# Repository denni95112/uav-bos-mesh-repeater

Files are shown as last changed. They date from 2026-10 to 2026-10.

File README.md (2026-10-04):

# UAV-BOS Mesh-Repeater

LoRa-Repeater für die [UAV-BOS-Tracker](https://github.com/denni95112/uav-bos-hardware-tracker).
Er sendet keine eigene Position und hat kein GPS.
Er leitet die Funkpakete der Tracker weiter, mit demselben Meshtastic-kompatiblen Protokoll
wie die Tracker-Firmware.

- Tracker: [uav-bos-hardware-tracker](https://github.com/denni95112/uav-bos-hardware-tracker)
- Hardware: Heltec **WiFi LoRa 32 V2**, 868 MHz (ESP32, SX1276, OLED)
- Firmware: PlatformIO + Arduino (`src/`)
- Gehäuse: OpenSCAD (`case/repeater_case.scad`), Druckdateien `case/base.stl` und `case/lid.stl`

Die 433-MHz- und 915-MHz-Varianten des Boards passen nicht. Das Frequenzband ist fest EU 868.

> **Firmware ganz einfach aufspielen:** Repeater per Micro-USB anschließen und auf
> [ubhtwf.open-drone-tools.de](https://ubhtwf.open-drone-tools.de/?board=repeater) auf **Installieren** klicken.
> Das funktioniert direkt im Browser (Google Chrome oder Microsoft Edge am PC), ohne Software-Installation.

## Betriebsarten

| Betriebsart | WLAN | LoRa |
|---|---|---|
| Repeater + WLAN | nur Config-AP, kein Router | leitet weiter |
| Repeater ohne WLAN | aus | leitet weiter |

Der Access Point heißt **`UAV-BOS-Repeater-XXXX`**. Die Seite ist `http://192.168.4.1`.
Beim ersten Start ist "Repeater + WLAN" aktiv, damit sich das Gerät einrichten lässt.

- **PRG kurz**: Betriebsart wechseln. Die Auswahl gilt 3 Sekunden nach dem letzten Druck.
- **PRG 3 Sekunden**: OLED an oder aus. Der Funk läuft weiter.

Aus "Repeater ohne WLAN" kommt man mit einem kurzen Tastendruck zurück zum Config-AP.

## Einrichtung

1. Repeater per Micro-USB an den PC (Datenkabel). Firmware im Browser aufspielen:
   [ubhtwf.open-drone-tools.de](https://ubhtwf.open-drone-tools.de/?board=repeater), **Installieren**.
   Falls kein Port erscheint: **PRG** halten, kurz **RST** drücken, **PRG** loslassen, erneut auf Installieren klicken.
   Alternativ mit PlatformIO, siehe [Bauen](#bauen).
2. Mit dem WLAN `UAV-BOS-Repeater-XXXX` verbinden und `http://192.168.4.1` öffnen.
3. Dieselben LoRa-Werte eintragen wie bei den Trackern:
   - Modemprofil (Standard LongFast)
   - Frequenz-Slot
   - Hop-Limit
   - Sendeleistung (2–17 oder **20 dBm**; 18 und 19 werden zu 17. Der Tracker-SX1262 darf 22)
   - Weiterleitung: "Alle Pakete", "Nur UAV-BOS-Tracker" oder "Keine"
   - Sendezeit für fremde Pakete
   - **Mesh-Schlüssel**, identisch zu den Trackern
4. Optional ein AP-Passwort (mindestens 8 Zeichen, Benutzer `admin`).
5. Speichern. Das Gerät startet neu.

Ohne denselben Schlüssel erkennt der Repeater den UAV-BOS-Kanal nicht. "Alle Pakete" leitet
fremde Meshtastic-Pakete trotzdem weiter. "Nur UAV-BOS-Tracker" braucht den Schlüssel.

Der Repeater schickt alle 15 Minuten ein Hello mit Hop 0, damit die Tracker ihn als eigenen
Relay erkennen. Das Hello wird nicht weitergeflutet.

## Funk

Gleiche Vorgaben wie die Tracker-Firmware:

- EU_868, Sync-Word `0x2B`, Präambel 16
- Profile ShortFast, ShortSlow, MediumFast, MediumSlow, LongFast, LongModerate, LongSlow
- 250-kHz-Profile senden auf 869,525 MHz. 125-kHz-Profile nutzen Slot 1 (869,4625 MHz) oder Slot 2 (869,5875 MHz)
- 10 % Sendezeit im Band 869,4–869,65 MHz. Fremde Pakete stoppen früher, Tracker-Pakete haben Vorrang
- Kanalname `UAV-BOS`

**Schlüssel in der Firmware (optional):** `MESH_PSK_B64` in `.env` (Vorlage `.env.example`) oder als
Umgebungsvariable. Ein Gerät ohne gespeicherten Schlüssel übernimmt ihn einmalig. Der Wert steht
lesbar in der Binärdatei. Solche Builds nicht veröffentlichen.

## Gehäuse (`case/repeater_case.scad`)

Für die Heltec WiFi LoRa 32 V2 und einen LiPo 35 × 20,1 × 6,5 mm. Der Akku liegt unter dem
Display-Ende, die Platine auf seitlichen Auflagen. Ohne Stiftleisten: eine gelötete Leiste ist
höher als der Deckel. Fertige Druckdateien liegen in `case/`: `base.stl` und `lid.stl`.

Außenmaße: 63,8 × 29,9 × 23,5 mm.

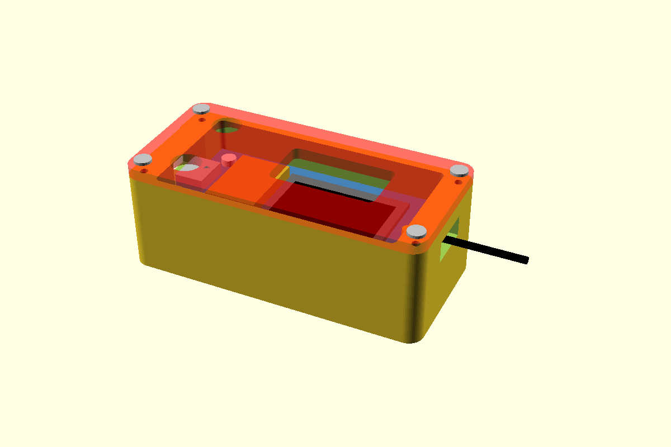
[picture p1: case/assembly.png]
Zusammenbau


Die Öffnungen sind an einem V2-Board gemessen, ab der Platinenkante an der USB-Seite.
"Links" heißt: von oben gesehen, USB-Buchse zeigt zu dir.

| Parameter | Standard / Bedeutung |
|---|---|
| `pcb_l`, `pcb_w` | 51 × 25,5 mm Platine |
| `bat_l`, `bat_w`, `bat_h` | 35 × 20,1 × 6,5 mm LiPo |
| `bottom_clear` | 4,8 mm Luft zwischen Akkuoberfläche und Platinenunterseite. Größer, wenn der Funkschirm den Akku berührt |
| `top_clear` | 7,0 mm über der Platinenoberseite für OLED und ESP32-Modul. Größer, wenn der Deckel auf das Display drückt |
| `oled_cx`, `oled_cy`, `oled_lx`, `oled_ly` | Displayfenster, Mitte ab USB-Kante und PRG-Kante |
| `prg_x`, `prg_y`, `rst_x`, `rst_y` | Tastenmitten. Das markierte Loch ist PRG |
| `usb_w`, `usb_h` | Micro-USB-Öffnung |
| `ant_w`, `ant_h` | Schlitz am Display-Ende für das U.FL-Antennenkabel |

Export:

```
openscad -o case/base.stl -D 'part="base"' case/repeater_case.scad
openscad -o case/lid.stl  -D 'part="lid"'  case/repeater_case.scad
```

`part="assembly"` zeigt das zusammengebaute Gerät mit Platine, Akku und Deckel.
`part="both"` legt Unterteil und Deckel nebeneinander zum Drucken.

Zusammenbau: Akku vom USB-Ende unter die beiden Lippen schieben und an der Buchse auf der
Unterseite einstecken. Platine gegen das Antennenende legen, Deckel aufsetzen und mit
4× M2×8 Zylinderkopfschrauben schließen. Die LoRa-Antenne führt durch den Schlitz am
Display-Ende nach außen. Das markierte Loch ist PRG (USB zeigt zu dir: links).

Druck in PETG oder PLA, 0,2 mm Schichthöhe, 3 Wände, keine Stützen. Der Deckel ist in der
STL schon kopfüber, die Oberseite liegt auf dem Druckbett.

## Bauen

```
pio run -e heltec_v2
pio run -e heltec_v2 -t upload
```

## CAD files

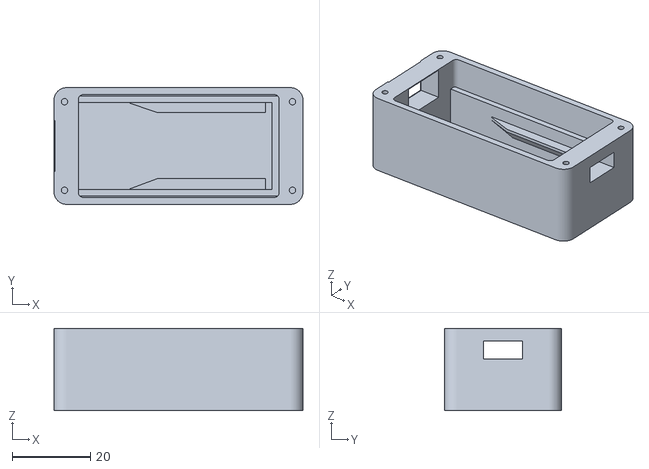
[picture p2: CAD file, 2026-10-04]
case/base.stl
63.8 x 29.9 x 21.1

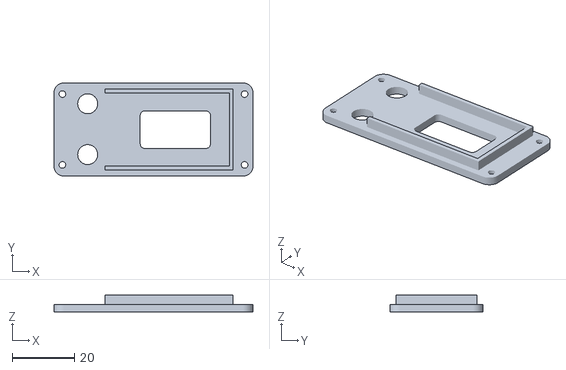
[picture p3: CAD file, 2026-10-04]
case/lid.stl
63.8 x 29.9 x 5.40

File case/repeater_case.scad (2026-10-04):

// Minimal case for the Heltec WiFi LoRa 32 V2 repeater and a 35 × 20.1 × 6.5 mm LiPo.
//
// The cell lies under the display end. The USB end stays open underneath so the
// SH1.25 plug and its wires fit. The PCB rests on side rails.
// No pin headers: a soldered header is taller than this lid.
//
// Seat the board against the antenna end so the window and the buttons line up.
// Slide the cell in from the USB end, under the two side lips, then plug it in
// and lay the board on the rails.
//
// Print base and lid in PLA or PETG, 0.2 mm layers, 3 perimeters, no supports.
// The lid is already flipped for printing (top face on the bed).
// Four M2×8 mm button-head screws, self-tapped into the end caps.
// The dotted hole is PRG (mode change, display on/off).
// With the USB port facing you, PRG is on the left.
//
// If the lid touches the display, raise top_clear.
// If the radio shield on the underside touches the cell, raise bottom_clear.

/* [Print] */
part = "both"; // [base, lid, both, assembly, preview]

/* [Board] */
pcb_l = 51.0;
pcb_w = 25.5;
pcb_t = 1.0;
bottom_clear = 4.8; // mm from cell top to PCB underside
top_clear = 7.0;    // mm above the PCB top, for the OLED and the ESP32 module

/* [Battery] */
bat_l = 35.0;
bat_w = 20.1;
bat_h = 6.5;

/* [Openings] */
// Centres are mm from the USB end of the PCB (x) and from the PRG edge (y).
oled_cx = 32.5;
oled_cy = 12.8;
oled_lx = 22.5; // along the board
oled_ly = 12.0; // across the board
prg_x = 4.4;
prg_y = 4.5;
rst_x = 4.4;
rst_y = 20.8;
btn_d = 6.4;
usb_w = 12.5;
usb_h = 8.0;
ant_w = 10.0;
ant_h = 4.5;

/* [Shell] */
wall = 1.8;
end_cap = 6.4;  // outer face to the PCB, each short end (holds an M2 screw)
floor_t = 1.8;
lid_t = 2.4;
lip_h = 3.0;
lip_t = 1.25;
lip_gap = 0.22;
corner_r = 3.2;
head_d = 3.8;   // M2 button head
head_h = 1.25;
pilot_d = 1.65;
clear_d = 2.15;
screw_inset_x = 2.7; // from the outer short face to the screw centre
screw_inset_y = 3.6; // from the outer long face

/* [Hidden] */
fn = 64;
play = 0.40;
bat_slack = 0.7;
bat_z_gap = 0.55;
bat_end_gap = 2.2;
rail_w = 1.6;
clip_reach = 2.8;
clip_t = 0.8;
pilot_depth = 7.5;

// ---- derived -------------------------------------------------------

pcb_x = end_cap;          // USB edge of the PCB
pcb_y = wall + play;      // PRG edge of the PCB
outer_l = end_cap + pcb_l + end_cap;
outer_w = pcb_y + pcb_w + play + wall;

cav_x = pcb_x - 0.12;
cav_y = wall;
cav_l = pcb_l + 0.12 + 0.28;
cav_w = outer_w - 2 * wall;

z_floor = floor_t;
z_pcb = z_floor + bat_h + bottom_clear;
z_top = z_pcb + pcb_t + top_clear;
base_h = z_top;
rail_h = z_pcb - z_floor;

bat_x1 = pcb_x + pcb_l - bat_end_gap;
bat_x0 = bat_x1 - bat_l - bat_slack;
bat_y0 = pcb_y + (pcb_w - bat_w) / 2;

module rounded_rect(l, w, h, r) {
    rr = min(r, min(l, w) / 2 - 0.01);
    hull()
        for (px = [rr, l - rr], py = [rr, w - rr])
            translate([px, py, 0])
                cylinder(h = h, r = rr, $fn = fn);
}

module screw_centers() {
    xs = [screw_inset_x, outer_l - screw_inset_x];
    ys = [screw_inset_y, outer_w - screw_inset_y];
    for (cx = xs, cy = ys)
        translate([cx, cy, 0])
            children();
}

module usb_cut() {
    // Jack on the PCB top. The mouth flares so a slightly recessed plug still fits.
    z0 = z_pcb + pcb_t - 1.2;
    y0 = pcb_y + pcb_w / 2 - usb_w / 2;
    translate([-1, y0, z0])
        cube([end_cap + 1.2, usb_w, usb_h]);
    hull() {
        translate([0.4, y0, z0])
            cube([0.2, usb_w, usb_h]);
        translate([-1.6, y0 - 1.5, z0 - 1.3])
            cube([0.2, usb_w + 3, usb_h + 2.5]);
    }
}

module ant_cut() {
    z0 = z_pcb + pcb_t - 0.8;
    y0 = pcb_y + pcb_w / 2 - ant_w / 2;
    translate([pcb_x + pcb_l - 0.4, y0, z0])
        cube([end_cap + 1, ant_w, ant_h]);
}

module button_holes() {
    for (p = [[prg_x, prg_y], [rst_x, rst_y]])
        translate([pcb_x + p[0], pcb_y + p[1], -lip_h - 1])
            cylinder(h = lid_t + lip_h + 2, d = btn_d, $fn = 40);
}

module oled_hole() {
    translate([pcb_x + oled_cx - oled_lx / 2,
               pcb_y + oled_cy - oled_ly / 2,
               -1])
        rounded_rect(oled_lx, oled_ly, lid_t + 2, 1.4);
}

module rails() {
    translate([cav_x, pcb_y, z_floor])
        cube([cav_l, rail_w, rail_h]);
    translate([cav_x, pcb_y + pcb_w - rail_w, z_floor])
        cube([cav_l, rail_w, rail_h]);
    translate([pcb_x + pcb_l - rail_w, pcb_y, z_floor])
        cube([rail_w + 0.2, pcb_w, rail_h]);
}

// Side lips the cell slides under. The underside is 45° so it prints without support.
module cell_clips() {
    z_tip = z_floor + bat_h + bat_z_gap;
    module one_lip(y_inner, sign) {
        y_tip = y_inner + sign * (clip_reach - 0.2);
        z_root = z_tip - clip_reach;
        module section(x, len) {
            hull() {
                translate([x, y_inner - (sign < 0 ? 0.2 : 0), z_root])
                    cube([len, 0.2, clip_reach + clip_t]);
                translate([x, y_tip, z_tip])
                    cube([len, 0.2, clip_t]);
            }
        }
        // Lead-in at the USB end, then a straight lip.
        hull() {
            translate([bat_x0, y_inner - (sign < 0 ? 0.2 : 0), z_tip])
                cube([0.2, 0.2, clip_t]);
            translate([bat_x0 + 7, y_inner - (sign < 0 ? 0.2 : 0), z_root])
                cube([0.2, 0.2, clip_reach + clip_t]);
            translate([bat_x0 + 7, y_tip, z_tip])
                cube([0.2, 0.2, clip_t]);
        }
        section(bat_x0 + 7, bat_x1 - bat_x0 - 8);
    }
    one_lip(pcb_y + rail_w, 1);
    one_lip(pcb_y + pcb_w - rail_w, -1);
}

module base() {
    difference() {
        union() {
            difference() {
                rounded_rect(outer_l, outer_w, base_h, corner_r);
                translate([cav_x, cav_y, z_floor])
                    rounded_rect(cav_l, cav_w, base_h, 1.15);
                usb_cut();
                ant_cut();
            }
            rails();
            cell_clips();
        }
        screw_centers()
            translate([0, 0, base_h - pilot_depth])
                cylinder(h = pilot_depth + 1, d = pilot_d, $fn = 28);
    }
}

module lip() {
    // Long sides and the antenna end. The USB end stays clear of the buttons.
    x0 = pcb_x + 10;
    y0 = cav_y + lip_gap;
    x1 = cav_x + cav_l - lip_gap;
    y1 = cav_y + cav_w - lip_gap;
    difference() {
        union() {
            translate([x0, y0, -lip_h])
                cube([x1 - x0, lip_t, lip_h]);
            translate([x0, y1 - lip_t, -lip_h])
                cube([x1 - x0, lip_t, lip_h]);
            translate([x1 - lip_t, y0, -lip_h])
                cube([lip_t, y1 - y0, lip_h]);
        }
        ant_cut();
    }
}

module lid() {
    difference() {
        union() {
            rounded_rect(outer_l, outer_w, lid_t, corner_r);
            lip();
        }
        screw_centers() {
            translate([0, 0, -1])
                cylinder(h = lid_t + 2, d = clear_d, $fn = 28);
            translate([0, 0, lid_t - head_h])
                cylinder(h = head_h + 1, d = head_d, $fn = 32);
        }
        button_holes();
        oled_hole();
        // Shallow mark: this hole is PRG.
        translate([pcb_x + prg_x + btn_d / 2 + 1.5,
                   pcb_y + prg_y,
                   lid_t - 0.4])
            cylinder(h = 0.5, d = 1.25, $fn = 24);
    }
}

module board_dummy() {
    pcb_top = z_pcb + pcb_t;
    color("steelblue")
        translate([pcb_x, pcb_y, z_pcb])
            cube([pcb_l, pcb_w, pcb_t]);
    color("dimgray")
        translate([pcb_x + oled_cx - 13.2, pcb_y + oled_cy - 8.6, pcb_top])
            cube([26.4, 17.2, 1.1]);
    color("black")
        translate([pcb_x + oled_cx - oled_lx / 2, pcb_y + oled_cy - oled_ly / 2, pcb_top + 0.9])
            cube([oled_lx, oled_ly, 0.35]);
    color("goldenrod")
        translate([pcb_x + 8, pcb_y + (pcb_w - 16) / 2, pcb_top])
            cube([11, 16, 3.1]);
    color("silver")
        translate([pcb_x - 1.4, pcb_y + pcb_w / 2 - 4, pcb_top])
            cube([6.2, 8, 2.6]);
    color("white")
        for (p = [[prg_x, prg_y], [rst_x, rst_y]])
            translate([pcb_x + p[0], pcb_y + p[1], pcb_top])
                cylinder(d = 3.2, h = 1.5, $fn = 24);
    color("gold")
        translate([pcb_x + pcb_l - 2.2, pcb_y + pcb_w / 2, pcb_top])
            cylinder(d = 2.4, h = 1.3, $fn = 20);
}

module cell_dummy() {
    color("dimgray")
        translate([bat_x0, bat_y0, z_floor])
            cube([bat_l, bat_w, bat_h]);
}

module screws_dummy() {
    color("silver")
        screw_centers() {
            translate([0, 0, base_h - 2.2])
                cylinder(d = 1.7, h = lid_t + 2.4, $fn = 16);
            translate([0, 0, base_h + lid_t - 0.15])
                cylinder(d = head_d - 0.15, h = 0.7, $fn = 24);
        }
}

module lid_print() {
    translate([0, 0, lid_t])
        rotate([180, 0, 0])
            lid();
}
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

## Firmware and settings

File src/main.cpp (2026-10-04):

#include <Arduino.h>
#include <WiFi.h>

#include "config.h"
#include "display.h"
#include "mesh.h"
#include "pins.h"
#include "portal.h"

#ifndef FW_VERSION
#define FW_VERSION "dev"
#endif

namespace {

constexpr uint32_t kBootScreenMs = 1500;
constexpr uint32_t kDebounceMs = 40;
constexpr uint32_t kDisplayHoldMs = 3000;
constexpr uint32_t kModeCommitMs = 3000;
constexpr uint32_t kDisplayRefreshMs = 500;

RepeaterConfig cfg;
String apSsid;

bool modeSelecting = false;
RepeaterMode selectedMode = RepeaterMode::WithWifi;
uint32_t modeSelectMs = 0;
uint32_t lastDisplayMs = 0;

String makeApSsid() {
  uint8_t mac[6];
  WiFi.macAddress(mac);
  char buf[32];
  snprintf(buf, sizeof(buf), "UAV-BOS-Repeater-%02X%02X", mac[4], mac[5]);
  return String(buf);
}

void enterRadioOnly() {
  portal::stop();
  WiFi.disconnect(true);
  WiFi.mode(WIFI_OFF);
  Serial.println("[main] repeater, WiFi off");
}

void enterWithWifi() {
  WiFi.persistent(false);
  WiFi.setHostname("uav-bos-repeater");
  portal::startAp(cfg, apSsid);
  Serial.println("[main] repeater, config AP");
}

void applyMode() {
  Serial.printf("[main] mode %s\n", config::modeName(cfg.mode));
  display::setMode(cfg.mode);
  if (cfg.usesWifi()) enterWithWifi();
  else enterRadioOnly();
}

void switchMode(RepeaterMode mode) {
  if (mode == cfg.mode) return;
  cfg.mode = mode;
  config::saveMode(mode);
  applyMode();
  lastDisplayMs = 0;
}

void handleWebModeRequest() {
  static bool pending = false;
  static RepeaterMode mode;
  static uint32_t requestMs = 0;
  RepeaterMode req;
  if (portal::takeModeRequest(req)) {
    pending = true;
    mode = req;
    requestMs = millis();
  }
  if (pending && millis() - requestMs >= 500) {
    pending = false;
    modeSelecting = false;
    switchMode(mode);
  }
}

enum class Button { None, Short, HoldDisplay };

Button pollButton() {
  static bool lastRaw = false;
  static bool pressed = false;
  static bool holdFired = false;
  static uint32_t changedMs = 0;
  static uint32_t pressedMs = 0;

  bool raw = digitalRead(PIN_BUTTON) == LOW;
  uint32_t now = millis();
  if (raw != lastRaw) {
    lastRaw = raw;
    changedMs = now;
  }
  if (now - changedMs < kDebounceMs) return Button::None;

  if (raw && !pressed) {
    pressed = true;
    holdFired = false;
    pressedMs = now;
  } else if (raw && pressed) {
    if (!holdFired && now - pressedMs >= kDisplayHoldMs) {
      holdFired = true;
      return Button::HoldDisplay;
    }
  } else if (!raw && pressed) {
    pressed = false;
    if (!holdFired) return Button::Short;
  }
  return Button::None;
}

void handleButton() {
  switch (pollButton()) {
  case Button::Short:
    display::setOn(true);
    selectedMode = config::nextMode(modeSelecting ? selectedMode : cfg.mode);
    modeSelecting = true;
    modeSelectMs = millis();
    lastDisplayMs = 0;
    break;
  case Button::HoldDisplay:
    modeSelecting = false;
    display::toggle();
    break;
  default:
    break;
  }

  if (modeSelecting && millis() - modeSelectMs >= kModeCommitMs) {
    modeSelecting = false;
    lastDisplayMs = 0;
    switchMode(selectedMode);
  }
}

void checkReboot() {
  if (!portal::rebootRequested()) return;
  display::showBoot("Neustart");
  delay(800);
  ESP.restart();
}

void updateDisplay() {
  uint32_t now = millis();
  if (lastDisplayMs && now - lastDisplayMs < kDisplayRefreshMs) return;
  lastDisplayMs = now;

  if (modeSelecting) {
    display::showModeSelect(selectedMode, cfg.mode, kModeCommitMs - min(kModeCommitMs, now - modeSelectMs));
    return;
  }
  int clients = cfg.usesWifi() ? portal::apClients() : -1;
  display::showStatus(mesh::stats(), clients);
}

} // namespace

void setup() {
  Serial.begin(115200);
  pinMode(PIN_BUTTON, INPUT_PULLUP);
  pinMode(PIN_LED, OUTPUT);
  digitalWrite(PIN_LED, LOW);

  display::begin();
  display::showBoot(FW_VERSION);

  config::load(cfg);
  mesh::begin(cfg.mesh, cfg.meshKey);
  mesh::setActive(true);

  WiFi.persistent(false);
  WiFi.setHostname("uav-bos-repeater");
  apSsid = makeApSsid();

  Serial.printf("\n[main] UAV-BOS repeater %s, AP name %s\n", FW_VERSION, apSsid.c_str());
  delay(kBootScreenMs);
  applyMode();
}

void loop() {
  handleButton();
  handleWebModeRequest();
  if (cfg.usesWifi()) {
    portal::loop();
    checkReboot();
  }
  updateDisplay();
  delay(2);
}

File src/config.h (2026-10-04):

#pragma once

#include <Arduino.h>

enum class RepeaterMode : uint8_t {
  WithWifi = 0,  // LoRa repeater, WiFi is the config AP only
  RadioOnly = 1, // LoRa repeater, WiFi off
};

// Meshtastic modem presets that fit the EU_868 sub-band 869.4-869.65 MHz.
enum class LoraPreset : uint8_t {
  ShortFast = 0,
  ShortSlow = 1,
  MediumFast = 2,
  MediumSlow = 3,
  LongFast = 4,
  LongModerate = 5,
  LongSlow = 6,
  Count
};

enum class RelayMode : uint8_t {
  All = 0,     // like Meshtastic rebroadcast mode ALL
  OwnOnly = 1, // only packets on the own tracker channel
  None = 2,
};

struct MeshSettings {
  LoraPreset preset = LoraPreset::LongFast;
  uint8_t slot = 0; // frequency slot, 0 = Meshtastic default for the preset
  uint8_t hopLimit = 3;
  int8_t txPowerDbm = 20;
  RelayMode relayMode = RelayMode::All;
  uint8_t foreignAirtimePct = 6; // foreign packets are relayed only below this share of airtime
};

struct RepeaterConfig {
  String apPass; // empty = open config AP
  RepeaterMode mode = RepeaterMode::WithWifi;
  MeshSettings mesh;
  String meshKey; // base64 channel key, same on all trackers of an organisation

  bool usesWifi() const { return mode == RepeaterMode::WithWifi; }
};

namespace config {

constexpr uint8_t kMaxSlot = 2;
constexpr uint8_t kMinHopLimit = 1;
constexpr uint8_t kMaxHopLimit = 7; // 3 bits in the Meshtastic header
constexpr int8_t kMinTxPowerDbm = 2;
constexpr int8_t kMaxTxPowerDbm = 20; // SX1276 PA_BOOST maximum
constexpr uint8_t kMaxForeignAirtimePct = 10;

// Used when neither NVS nor the build provides a mesh key; the UI warns about it.
constexpr const char *kPlaceholderMeshKey = "CHANGE+ME+CHANGE+ME+CHANGE+ME+CHANGE+ME+CEE=";

// Clamps every field to its valid range.
MeshSettings sanitize(MeshSettings s);
// Base64 that decodes to a 16 or 32 byte AES key.
bool validMeshKey(const String &b64);

void load(RepeaterConfig &cfg);
void save(const RepeaterConfig &cfg);
void saveMode(RepeaterMode mode);
void clear();

RepeaterMode nextMode(RepeaterMode mode);
const char *modeName(RepeaterMode mode);  // long German name for the UI
const char *modeShort(RepeaterMode mode); // badge text

} // namespace config

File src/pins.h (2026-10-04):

#pragma once

// Heltec WiFi LoRa 32 V2 (ESP32 + SX1276 + SSD1306). 868 MHz module.
// Cross-checked with the Meshtastic heltec_v2 variant.

// Powers the OLED. Active LOW.
#define PIN_VEXT 21
#define VEXT_ON LOW

// SSD1306 128x64 OLED on I2C.
#define PIN_OLED_SDA 4
#define PIN_OLED_SCL 15
#define PIN_OLED_RST 16
#define OLED_ADDR 0x3C

// User button (PRG), active LOW.
#define PIN_BUTTON 0

#define PIN_LED 25

// Battery divider is 220k/100k (scale 3.2) and is connected while Vext is on.
// V2.0 senses on GPIO 13 (ADC2, only valid with WiFi off). V2.1 moved it to GPIO 37.
#define PIN_BATTERY_V2 13
#define PIN_BATTERY_V21 37

// SX1276 LoRa. DIO0 is RxDone / TxDone / CAD. No TCXO and no DIO2 RF switch.
#define PIN_LORA_SCK 5
#define PIN_LORA_MISO 19
#define PIN_LORA_MOSI 27
#define PIN_LORA_CS 18
#define PIN_LORA_RST 14
#define PIN_LORA_DIO0 26
#define PIN_LORA_DIO1 35

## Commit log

2026-10-04 case + bat level
    [base.stl, lid.stl, repeater_case.scad]
2026-11-01 Update section header for case information in README
